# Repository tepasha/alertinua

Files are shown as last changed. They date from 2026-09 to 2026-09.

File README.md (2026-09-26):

<div align="center">

# 🚨 alertinua

**Автономна система сповіщення про повітряні тривоги в Україні на базі мікроконтролера ESP32.**






[Опис](#-опис-проєкту) •
[Підключення](#-підключення) •
[Збірка](#-збірка-й-прошивка) •
[Налаштування](#-налаштування-пристрою) •
[Архітектура](#-архітектура) •
[Тести](#-тести)

---

</div>

## 📌 Опис проєкту

**`alertinua`** — прошивка для плати **LILYGO T-Display** (ESP32, дисплей
ST7789 240×135), написана на **ESP-IDF** з FreeRTOS. Пристрій сам
підключається до Wi-Fi, раз на хвилину опитує API
[alerts.in.ua](https://alerts.in.ua/) і показує на дисплеї карту України:

| На екрані | Що означає |
| --- | --- |
| 🟥 червона область | повітряна тривога по всій області |
| 🟧 янтарна область | тривога лише в частині області (район, громада) |
| напис **ERR** | дані отримати не вдалося — старі тривоги не показуються |

Коли тривога оголошена на всю **вибрану** область, вмикається сирена
(п'єзозумер) і блимає світлодіод. Яскравість підсвітки автоматично
підлаштовується під освітлення в кімнаті. Від вбудованого акумулятора
пристрій працює без USB, а рівень заряду видно на сторінці налаштувань.

## ✨ Особливості

- 🧠 **FreeRTOS:** 7 задач, кожна зі своєю відповідальністю, обмін через
  черги, спільний стан під м'ютексом — [docs/ARCHITECTURE.md](docs/ARCHITECTURE.md).
- 📡 **Легкий обмін з API:** IoT-ендпоінт alerts.in.ua повертає рядок із
  27 символів (`A`/`P`/`N` на кожну область) — ~30 байт замість кілобайтів
  JSON, лише повітряні тривоги.
- 🌐 **Веб-налаштування:** вибір області й Wi-Fi-мережі на сторінці
  пристрою, без перепрошивки. Зберігається в NVS.
- 💡 **Адаптивна яскравість:** фоторезистор + ПІ-регулятор з anti-windup
  керує підсвіткою через ШІМ.
- 🔋 **Автономність:** акумулятор Li-Pol 3.7 В 300 мА·год у штатному
  роз'ємі плати; заряд (%, В) — на веб-сторінці й у лозі.
- 🛡️ **Надійність:** Task Watchdog на кожній задачі, валідація відповіді
  API, перепідключення Wi-Fi з експоненційною затримкою (2 → 60 с).
- 🔐 **Секрети поза git:** API-токен у файлі `.env`, TLS з перевіркою
  сертифіката.

## 🔌 Підключення

Схема підключення

| Периферія | Деталі | GPIO | Компонент коду |
| --- | --- | --- | --- |
| Дисплей ST7789 (SPI) | вбудований: MOSI / SCLK / CS / DC / RST | 19 / 18 / 5 / 16 / 23 | `map` |
| Підсвітка дисплея | вбудована, ШІМ (LEDC) | 4 | `backlight` |
| Кнопка налаштування | вбудована кнопка BOOT, переривання | 0 | `button` |
| П'єзозумер | пасивний, через резистор 220 Ом, ШІМ (LEDC) | 25 | `buzzer` |
| Світлодіод тривоги | через резистор 330 Ом | 2 | `indicators` |
| Світлодіод Wi-Fi | через резистор 330 Ом | 15 | `indicators` |
| Датчик освітлення | фоторезистор + резистор 10 кОм, ADC1_CH5 | 33 | `light_sensor` |
| Акумулятор Li-Pol | у штатний роз'єм BAT; напругу плата подає через дільник 1:2, дільник вмикає GPIO14 | 34 (АЦП), 14 (внутрішні) | `battery` |
| Вимикач живлення | з фіксацією, розриває червоний провід «+» акумулятора | — | — |

**Що потрібно докупити:** фоторезистор, резистори 10 кОм, 220 Ом і
2 × 330 Ом, два світлодіоди, пасивний п'єзозумер, акумулятор Li-Pol
602030 3.7 В 300 мА·год із платою захисту, вимикач із фіксацією
(перемикач або клавішний) для живлення від акумулятора. Без світлодіодів
прошивка працює як звичайно. Без датчика вхід GPIO33 «висить у повітрі»,
і яскравість підсвітки стрибатиме випадково — тож для автояскравості
датчик потрібен.

> Перед підключенням акумулятора звірте роз'єм і **полярність** з
> маркуванням `+`/`−` на платі: у дешевих акумуляторів дроти в роз'ємі
> бувають переставлені, а переплутана полярність може пошкодити плату.
> Вимикач ставиться в розрив червоного проводу «+». Від USB плата
> працює й при вимкненому вимикачі, але батарея тоді не заряджається.

> Датчик освітлення підключайте лише до пінів ADC1 (32, 33, 36–39): ADC2
> під час роботи Wi-Fi недоступний. GPIO34 на гребінку не виведений — він
> зайнятий вимірюванням напруги батареї.

Опис схеми й вибору деталей — [docs/PCB.md](docs/PCB.md).

## 🛠️ Збірка й прошивка

Потрібні [VS Code](https://code.visualstudio.com/) з розширенням
**PlatformIO**. Платформа `espressif32` встановлює ESP-IDF (перевірено на
6.0.1) і тулчейн сама.

1. **Токен API.** Отримайте токен на [alerts.in.ua](https://alerts.in.ua/),
   скопіюйте `.env.example` у `.env` і впишіть його:
   ```
   ALERTINUA_API_TOKEN=ваш-токен
   ```
   `.env` і згенерований з нього `env/env_config.h` у `.gitignore` —
   токен не потрапляє в git.
2. **Wi-Fi за замовчуванням (необов'язково).** Мережу простіше задати
   через [веб-налаштування](#-налаштування-пристрою). Або заздалегідь у
   `pio run -t menuconfig` → *Alertinua Configuration → Wi-Fi*.
3. **Збірка й прошивка:**
   ```
   pio run -t upload
   pio device monitor
   ```

Інші параметри (область за замовчуванням, інтервал опитування, межі
яскравості, максимальна тривалість сирени) — у
`pio run -t menuconfig` → *Alertinua Configuration*.

## ⚙️ Налаштування пристрою

1. Утримайте кнопку **BOOT** 3 секунди. Пристрій також сам переходить у
   цей режим після 10 невдалих спроб підключитися до Wi-Fi.
2. Підключіться до Wi-Fi-мережі **ESP32-Setup**.
3. Відкрийте **http://192.168.4.1/**.
4. Угорі сторінки — заряд батареї (%, В) або «Живлення від USB». Виберіть область. Щоб змінити Wi-Fi, впишіть SSID і пароль; якщо лишити
   SSID порожнім, збережена мережа не зміниться.
5. Натисніть **«Зберегти і перезавантажити»**.

## 🧩 Архітектура

```
API alerts.in.ua ──► fetch_task ──► alert_queue ──► render_task ──► дисплей
        ▲                                               │
    wifi_task                                           └──► buzzer_task (сирена)

фоторезистор ──► brightness_task (ПІ-регулятор) ──► підсвітка (ШІМ)
кнопка BOOT ──► button_task ──► режим налаштування
monitor_task: раз на 30 с — навантаження CPU кожної задачі і заряд батареї
```

Структура проєкту:

```
task/          задачі FreeRTOS — по підпапці-компоненту на кожну
components/    драйвери й логіка без власних задач:
               adc_shared, app_state, backlight, battery, brightness_ctrl,
               button, buzzer, indicators, light_sensor, map, scraping,
               settings, wifi_manager
src/           app_main() і Kconfig.projbuild (параметри menuconfig)
env/           env.py: .env → env/env_config.h перед кожною збіркою
test_host/     юніт-тести, що запускаються на комп'ютері
test_apps/     юніт-тести для запуску на самій платі
docs/          архітектура, схема підключення, опис апаратної частини
```

Детально — [docs/ARCHITECTURE.md](docs/ARCHITECTURE.md).

## 🧪 Тести

Парсер відповіді API, ПІ-регулятор яскравості і крива заряду батареї —
«чисті» функції без
залежності від обладнання, тому тестуються на звичайному комп'ютері
(фреймворк Unity):

```
sudo apt-get install --no-install-recommends libcjson-dev
make -C test_host run
```

Набір для запуску на платі — у `test_apps/` (див. коментар у
`test_apps/test_main.c`).

<div align="center">

### Слава Україні! 🇺🇦

</div>

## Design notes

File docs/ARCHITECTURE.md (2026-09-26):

# Архітектура

## 1. Чому RTOS, а не superloop

Пристрою потрібно одночасно: тримати Wi-Fi (з перепідключенням), періодично
опитувати зовнішнє REST API (мережевий I/O з тайм-аутами до 10с), малювати на
дисплеї, регулювати яскравість підсвітки за датчиком світла кожні ~0.5с,
реагувати на кнопку без затримки і керувати зумером — без того, щоб повільна
операція (HTTP-запит) блокувала швидку (регулювання яскравості, кнопка).
Один superloop із чергою `if`-ів або з `delay()` не дав би цього без
кооперативної диспетчеризації, яку FreeRTOS вже надає готовою. Тому вибір —
**FreeRTOS (RTOS)**, з окремою задачею на кожну незалежну відповідальність.

## 2. Задачі (FreeRTOS tasks)

Усі задачі лежать у папці `task/` у корені проєкту — кожна у власній
підпапці, яка є окремим компонентом ESP-IDF (`task/fetch_task/`, …).
Решта компонентів — драйвери й чиста логіка без власних задач.

| Задача | Папка (`task/`) | Пріоритет | Блокується на | Головна робота |
|---|---|---|---|---|
| `wifi_task` | `wifi_task/` | 4 | event group (тайм-аут) | підключення/перепідключення Wi-Fi, backoff, auto-provisioning |
| `fetch_task` | `fetch_task/` | 4 | `vTaskDelay` (період опитування) | HTTP GET + JSON-парсинг, шле у `alert_queue` |
| `render_task` | `render_task/` | 5 | `xQueueReceive(alert_queue)` | єдиний "письменник" framebuffer/дисплей |
| `button_task` | `button_task/` | 5 | `xQueueReceive` (ISR events) | дебаунс + вимірювання тривалості натискання |
| `buzzer_task` | `buzzer_task/` | 4 | `xQueueReceive` (команди) | неблокуюча сирена/біп |
| `brightness_ctrl_task` | `brightness_task/` | 3 | `vTaskDelay` (період регулятора) | PI-регулятор яскравості за датчиком світла |
| `monitor_task` | `monitor_task/` | 1 | `vTaskDelay` (30с) | CPU usage stats, watchdog-звіт |
| `indicators` (esp_timer callback) | indicators | — | апаратний таймер | блимання Status/Wi-Fi LED |

Мінімум "2 tasks" із п.3.1 виконано з запасом (7 задач + 1 періодичний
таймер). Кожна задача, що виконує повторювану роботу, підписана на **Task
Watchdog Timer** (`esp_task_wdt_add` + періодичний `esp_task_wdt_reset`) —
якщо якась задача зависне, пристрій сам перезавантажиться (п.5.1).

## 3. Синхронізація

```mermaid
flowchart LR
    subgraph Producers
        WT[wifi_task]
        FT[fetch_task]
        BT[button_task]
        BC[brightness_ctrl_task]
    end

    subgraph Shared["app_state (mutex-захищена структура)"]
        M((mutex))
    end

    subgraph Consumers
        RT[render_task]
        IND[indicators timer]
        MON[monitor_task]
    end

    WT -- app_state_set_wifi_status --> M
    FT -- app_state_set_alarm / set / record_fetch --> M
    BC -- app_state_set_brightness --> M
    M -- app_state_get_* --> IND
    M -- app_state_get_fetch_stats --> MON

    FT -- "alert_queue (struct, async buffer)" --> RT
    BT -. "ISR queue (gpio events)" .-> BT
    RT -- buzzer_start_alarm/stop_alarm --> BZ[buzzer_task]
```

- **Mutex** (`app_state`, `SemaphoreHandle_t`) — єдина точка правди про стан
  системи (Wi-Fi статус, чи активна тривога, яка область, яскравість,
  статистика останнього опитування). Пишуть у неї 3 різні задачі, читають —
  ще 3 інші. Критичні секції короткі (лише memcpy кількох полів), тайм-аут
  очікування mutex — 200мс (див. `app_state.c`), щоб зависання одного
  читача/писача було помітним у логах, а не тихим deadlock.
- **Queue** використано двічі, з різним призначенням:
  - `button` ISR → `button_task` (сирі події зміни рівня GPIO);
  - `fetch_task` → `render_task` (`alert_queue`, готовий результат циклу
    опитування — це і є "асинхронна передача даних" з п.2.4/3.2).
  - `buzzer` командна черга (`buzzer_task` чекає команд start/stop/beep).
- Жодна задача не читає/пише framebuffer дисплея, крім `render_task` —
  тому для нього окремий mutex не потрібен (єдиний писар за конструкцією,
  а не за домовленістю).

## 4. Діаграма станів (`app_state_t`)

```mermaid
stateDiagram-v2
    [*] --> BOOT
    BOOT --> WIFI_CONNECTING
    WIFI_CONNECTING --> FETCHING: Wi-Fi підключено
    WIFI_CONNECTING --> PROVISIONING: N невдалих спроб підряд\n(або довге натискання кнопки)
    FETCHING --> ALARM: тривога у вибраній області
    FETCHING --> CLEAR: тривоги немає
    FETCHING --> ERROR: HTTP/JSON помилка
    ALARM --> FETCHING: наступний цикл опитування
    CLEAR --> FETCHING: наступний цикл опитування
    ERROR --> FETCHING: наступний цикл опитування
    PROVISIONING --> [*]: користувач зберіг Wi-Fi\n(esp_restart)
```

`app_state_set()` (у `components/app_state`) логує кожен перехід
(`state: X -> Y`), що зручно і для налагодження, і як "живий" доказ роботи
state machine під час демонстрації (п.9.3).

## 5. Дані датчика світла → підсвітка (feedback control, п.4.1/4.2)

```mermaid
flowchart LR
    LDR[LDR + дільник\nGPIO33 / ADC1_CH5] -->|"light_sensor_read_normalized()\n0.0..1.0"| CTRL
    CTRL["PI-регулятор\n(brightness_ctrl_task)"] -->|"backlight_set_percent()"| PWM[LEDC PWM\nGPIO4]
    PWM --> BL[Підсвітка дисплея]
    CTRL -->|"app_state_set_brightness()"| STATE[(app_state)]
```

`setpoint = min + lux*(max-min)`, `error = setpoint - поточна_яскравість`,
далі класичний PI із анти-windup (обмеження інтегральної складової) і
насиченням виходу в межах `[MIN, MAX]` (Kconfig). Деталі й коефіцієнти —
`components/brightness_ctrl/brightness_ctrl_step.c` (чиста функція, покрита
хост-тестами), періодичний цикл — `task/brightness_task/brightness_task.c`.

## 6. Граф залежностей компонентів

Компоненти навмисно розбиті так, щоб не було циклів, і кожен ізольований
модуль (`button`, `buzzer`, `backlight`, `light_sensor`, `map`) не знав нічого
про решту системи — вони отримують дані через параметри функцій або нічого
не знають про `app_state` взагалі.

```mermaid
flowchart TD
    main --> app_state
    main --> indicators
    main --> wifi_manager
    main --> wifi_task
    main --> fetch_task
    main --> render_task
    main --> button_task
    main --> buzzer_task
    main --> brightness_task
    main --> monitor_task

    wifi_task --> wifi_manager
    wifi_manager --> settings
    wifi_manager --> scraping
    fetch_task --> settings
    wifi_task --> app_state
    fetch_task --> scraping
    fetch_task --> app_state
    render_task --> map
    render_task --> fetch_task
    render_task --> buzzer_task
    button_task --> button
    buzzer_task --> buzzer
    brightness_task --> brightness_ctrl
    brightness_task --> light_sensor
    brightness_task --> backlight
    brightness_task --> app_state
    monitor_task --> app_state
    monitor_task --> battery
    wifi_manager --> battery
    battery --> adc_shared
    light_sensor --> adc_shared

    indicators --> app_state
    scraping --> map
```

## 7. Відображення на дисплеї

Дані беруться з IoT-ендпоінта alerts.in.ua
`/v1/iot/active_air_raid_alerts_by_oblast.json` — це рядок із 27 символів
(`A` — тривога по всій області, `P` — у частині області, `N` — немає),
розбирається в `components/scraping/alerts_parser.c`.

`render_task` — єдина задача, що малює. Кожен кадр малюється з нуля
(`components/map/map_render.c`):
- `render_map()` — базова штрихована мапа;
- `render_mark_regions_partial()` — часткова тривога, янтарна заливка;
- `render_mark_regions_red()` — тривога по всій області, червона заливка;
- `render_draw_err_banner()` — помилка HTTP/розбору: поверх базової мапи
  лише напис "ERR", без застарілих тривог.

Міста "м. Київ" і "м. Севастополь" окремих полігонів не мають — тривога в
них показується як часткова у Київській області / Криму.

## 8. Відомі свідомі спрощення (не приховуємо)

- `wifi_manager_start_provisioning()` можна викликати і з довгого натискання
  кнопки, і автоматично з `wifi_task` після N невдалих спроб — обидва шляхи
  не координуються через окрему чергу/семафор (в оригінальному коді цей же
  ризик уже був). Малоймовірна гонитва при одночасному спрацюванні обох
  тригерів не призводить до пошкодження даних (лише до зайвого логу),
  оскільки `s_provisioning_active` перевіряється перед стартом SoftAP.
- Один HTTP-буфер (8КБ, `static` у `fetch_task`) виділений один раз назавжди,
  а не на кожен цикл — свідомо, щоб уникнути фрагментації купи (heap) і
  повторних malloc/free (п.6.3).

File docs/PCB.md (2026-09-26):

# Апаратна частина

## Схема підключення

Схема підключення

`docs/wiring.svg` — схема з'єднань зовнішніх деталей з гребінкою LILYGO
T-Display. Дисплей, його підсвітка й кнопка BOOT уже є на платі.
Принципова схема в KiCad — у роботі.

## Що на схемі

| Позначення | Що це | GPIO | Примітка |
|---|---|---|---|
| BUZ1 | П'єзозумер | GPIO25 (LEDC, PWM) | R1 (220R) обмежує струм через п'єзоелемент |
| ST7789 (BL) | Підсвітка дисплея | GPIO4 (LEDC, PWM) | вбудована; керується `brightness_task` (ПІ-регулятор) |
| SW1 | Кнопка входу в налаштування Wi-Fi | GPIO0 | вбудована BOOT-кнопка плати, зовнішня не потрібна |
| LED1 + R2 | Індикатор тривоги | GPIO2 | R2 330 Ом обмежує струм; блимає, поки тривога активна |
| LED2 + R3 | Індикатор Wi-Fi | GPIO15 | R3 330 Ом; горить постійно / блимає / вимкнено залежно від статусу |
| LDR1 + R4 | Дільник напруги з фоторезистором (датчик освітлення) | GPIO33 (ADC1_CH5) | R4 10 кОм; ADC1, бо ADC2 не працює разом із Wi-Fi |
| SW2 | Вимикач живлення з фіксацією | — | у розриві червоного проводу «+» між акумулятором і роз'ємом BAT; при вимкненому SW2 плата живиться лише від USB, батарея не заряджається |
| BAT1 | Акумулятор Li-Pol 602030, 3.7 В, 300 мА·год, з платою захисту | GPIO34 (ADC1_CH6), GPIO14 | у штатний роз'єм BAT; заряджає вбудований контролер від USB. Напругу плата подає на GPIO34 через дільник 100к/100к, дільник вмикається HIGH на GPIO14 |

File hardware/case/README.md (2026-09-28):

# Корпус alertinua для 3D-друку

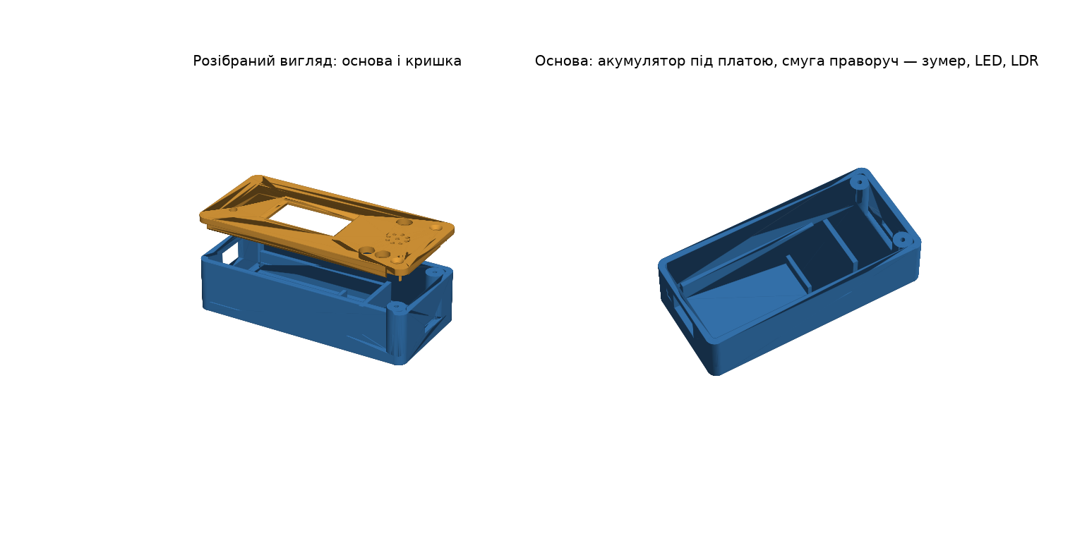
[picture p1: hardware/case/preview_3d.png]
Прев'ю


Компактний корпус **76 × 36 × 20 мм** із двох частин. Акумулятор лежить
**під платою**, між напрямними, тому праворуч від плати лишається лише
вузька смуга під зумер, світлодіоди, фоторезистор і вимикач.

- **основа** — напрямні під LILYGO T-Display (висота 7 мм), під ними —
  акумулятор 602030 з упором, отвір під USB-C (зліва), проріз під вимикач
  SS-12D00 (справа, внизу), 2 стійки під саморізи M2 у правих кутах;
- **кришка** — вікно екрана з фаскою, отвір ⌀3 мм до кнопки BOOT, 2 отвори
  під світлодіоди 5 мм, отвір під фоторезистор 5 мм, решітка й тримач
  зумера ⌀12 мм, посадковий бортик. Ліву частину кришки тримає бортик,
  праву — 2 гвинти M2.

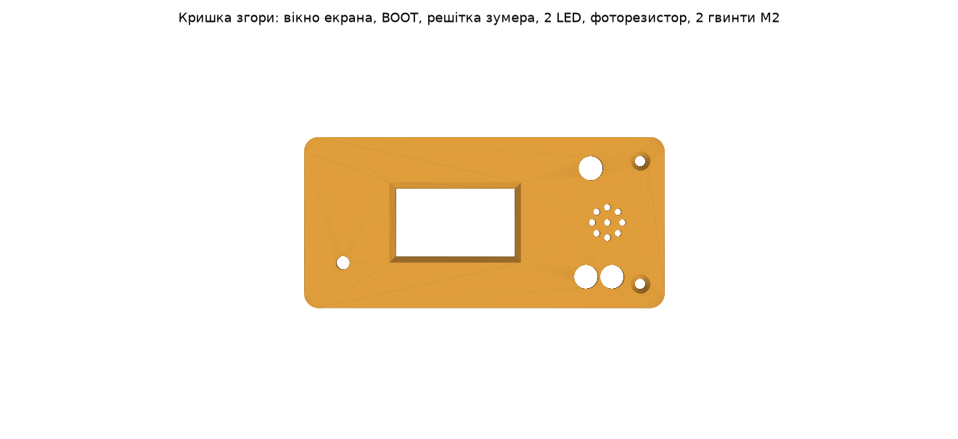
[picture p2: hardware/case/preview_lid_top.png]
Кришка згори


## Файли

| Файл | Для чого |
| --- | --- |
| `alertinua_base.stl`, `alertinua_lid.stl` | слайсер; вже в положенні для друку (основа дном, кришка лицем на столі) |
| `alertinua_case.FCStd` | редагування у FreeCAD |
| `alertinua_base.step`, `alertinua_lid.step` | інші CAD-програми |
| `alertinua_case.py` | параметричний скрипт, з якого згенеровано все вище |

## Перед друком — виміряти

Ці розміри в скрипті — оцінки (позначені `ВИМІРЯТИ`). Звірте їх
штангенциркулем, змініть у `alertinua_case.py` і перегенеруйте:

1. `DISP_CX`, `DISP_CY` — центр екрана на платі (найважливіше).
2. `BOOT_X`, `BOOT_Y` — положення кнопки BOOT.
3. `USB_CZ` — висота роз'єму USB-C над дном (отвір має запас).
4. `BUZ_D` — діаметр зумера (зараз 12 мм).
5. `BATT_L` — довжина акумулятора разом із платою захисту (зараз 34 мм).
6. **Що стирчить знизу плати.** Під платою лишається 7 мм, акумулятор —
   6 мм. Якщо роз'єм BAT чи інші деталі на звороті T-Display виступають
   більше ніж на 1 мм, збільште `IN_H`
   (висоту корпусу) на потрібну величину.

Перегенерувати:

```
freecadcmd alertinua_case.py
```

Файли з'являться в папці `out/` поруч зі скриптом.

## Друк

PLA або PETG, шар 0.2 мм, заповнення 20 %, без підтримок. Спершу варто
надрукувати лише кришку й приміряти до плати — це швидко покаже, чи
правильно стоїть вікно екрана.

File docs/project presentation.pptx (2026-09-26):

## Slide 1

ДИПЛОМНИЙ ПРОЄКТ

alertinua

Розробка вбудованої системи моніторингу повітряних тривог на базі мікроконтролера ESP32

Терехов Павло

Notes: Шановні члени екзаменаційної комісії! Мене звати [ПІБ], я студент групи [група]. Представляю дипломний проєкт на тему «Розробка вбудованої системи моніторингу повітряних тривог на базі мікроконтролера ESP32». Мій науковий керівник — [ПІБ керівника].

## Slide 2

АКТУАЛЬНІСТЬ

Навіщо окремий пристрій

Телефон не завжди поруч

Розряджений, у беззвучному режимі або в іншій кімнаті.

Карта з першого погляду

Стан усіх областей одразу, без відкривання застосунків.

Надійність критична

Зависання чи застарілі дані для сповіщувача неприйнятні.

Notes: Повітряна тривога в Україні — частина щоденного життя. Люди стежать за нею через застосунки на смартфоні, але телефон буває розряджений, у беззвучному режимі або просто не під рукою. Потрібен окремий пристрій, який постійно працює, наприклад на столі чи біля входу. Він має з першого погляду показувати ситуацію по всій країні й подавати звуковий сигнал, коли тривога у вашій області. Готові рішення на кшталт настінних мап існують, але їх зазвичай роблять як аматорські проєкти. Там мало уваги приділяють надійності: пристрій може зависнути під час обриву Wi-Fi чи після некоректної відповіді сервера, і тоді показує застарілі дані. Для пристрою, який сповіщає про небезпеку, це неприйнятно.

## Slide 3

МЕТА І ЗАДАЧІ

Автономний пристрій, що в реальному часі показує карту повітряних тривог України і стабільно працює без втручання користувача.

01

Дані з API alerts.in.ua

02

Карта областей з тривогами

03

Сирена для вибраної області

04

Налаштування без перепрошивки

05

Стабільність при збоях мережі й сервера

06

Автоматичні тести ключової логіки

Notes: Мета роботи — розробити автономний пристрій, який у реальному часі показує карту повітряних тривог України і стабільно працює без втручання користувача. Для цього я поставив такі задачі: отримувати дані з офіційного API сервісу alerts.in.ua; відображати на дисплеї карту областей з тривогами; сповіщати звуком про тривогу у вибраній області; забезпечити налаштування пристрою без перепрошивки; гарантувати стабільну роботу при збоях мережі й сервера; покрити ключову логіку автоматичними тестами.

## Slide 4

АПАРАТНА ЧАСТИНА

LILYGO T-Display на ESP32

Компонент | Призначення | GPIO
П'єзозумер | сирена, ШІМ | 25
Фоторезистор | автояскравість, АЦП | 33
Підсвітка | яскравість, ШІМ | 4
Кнопка BOOT | режим налаштування | 0
Світлодіоди | стан і Wi-Fi | 2, 15
Акумулятор Li-Pol | автономність, заряд у веб | 34

Вбудований Wi-Fi, два ядра й апаратний TLS за невисокої ціни.

Кольоровий дисплей ST7789, 240×135 пікселів.

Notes: Основа пристрою — плата LILYGO T-Display з мікроконтролером ESP32 і кольоровим дисплеєм ST7789 на 240×135 пікселів. ESP32 я вибрав, бо він має вбудований Wi-Fi, два ядра й апаратну підтримку TLS за невисокої ціни. До плати підключено: п'єзозумер для сирени, що керується через ШІМ (модуль LEDC); фоторезистор на вході АЦП для автоматичного регулювання яскравості; два світлодіоди для індикації стану системи й Wi-Fi; вбудовану кнопку BOOT, через яку вмикається режим налаштування; акумулятор Li-Pol 602030 на 3.7 В і 300 мА·год із платою захисту — у штатний роз'єм плати, його заряд плата вимірює на GPIO34 і показує на веб-сторінці.

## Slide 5

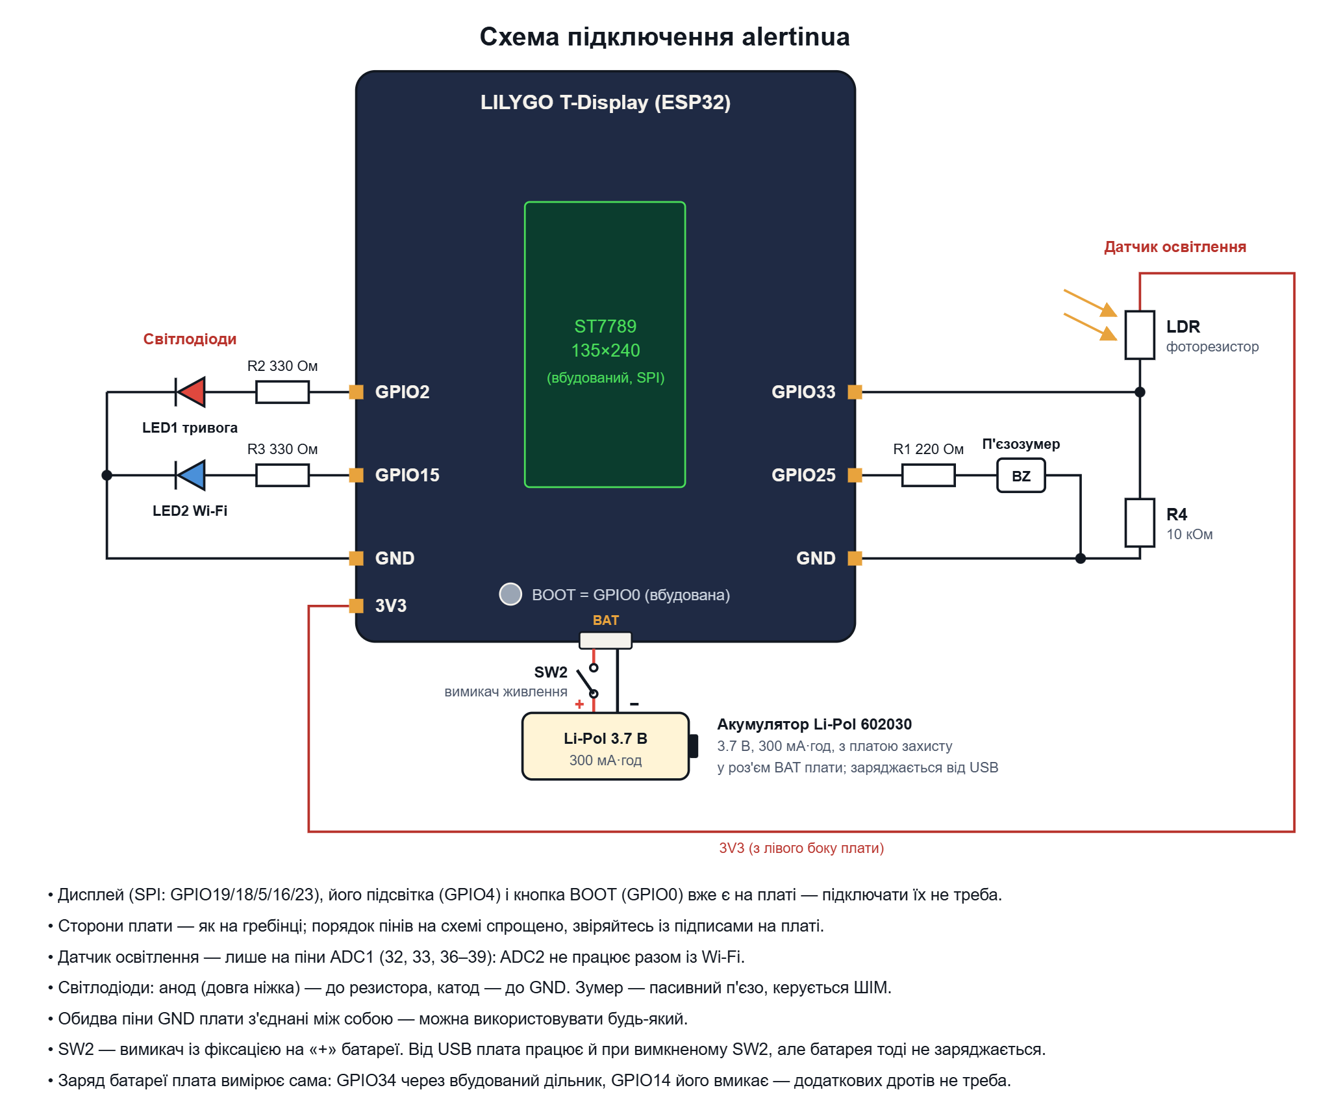
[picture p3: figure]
Схема підключення: фоторезистор і резистор 10 кОм до GPIO33, зумер через 220 Ом до GPIO25, світлодіоди через 330 Ом до GPIO2 і GPIO15, акумулятор Li-Pol через вимикач у роз'єм BAT

СХЕМА ПІДКЛЮЧЕННЯ

Що підключається до плати

Дисплей, підсвітка й кнопка BOOT уже є на платі.

Фоторезистор — на ADC1 (GPIO33), бо ADC2 не працює разом із Wi-Fi.

Акумулятор — у штатний роз'єм BAT, через вимикач на «+».

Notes: Зовнішніх деталей небагато. Дисплей, його підсвітка й кнопка BOOT уже є на самій платі. Ліворуч, біля GPIO2 і GPIO15, — світлодіоди: тривоги через резистор 330 Ом на GPIO2 і Wi-Fi через 330 Ом на GPIO15. Праворуч — датчик освітлення і зумер. Фоторезистор і резистор 10 кОм утворюють дільник напруги, середня точка йде на GPIO33 — це вхід ADC1, бо АЦП другого блоку під час роботи Wi-Fi недоступний. Живлення 3V3 для дільника береться з лівого боку плати. Пасивний п'єзозумер підключено через резистор 220 Ом до GPIO25 (ШІМ). Знизу — акумулятор Li-Pol 602030, 3.7 В, 300 мА·год із платою захисту. Він вставляється у штатний роз'єм BAT, заряджається від USB вбудованим контролером. Напругу батареї плата подає на GPIO34 через дільник, тож для показника заряду додаткові дроти не потрібні. У розриві червоного проводу «+» стоїть вимикач живлення з фіксацією SW2: ним пристрій вимикається, коли працює від батареї.

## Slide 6

АРХІТЕКТУРА ПЗ

7 задач FreeRTOS на ESP-IDF

API alerts.in.ua

fetch_task

alert_queue

render_task

Дисплей і сирена

Паралельно працюють:

wifi_task

Wi-Fi і перепідключення

buzzer_task

неблокуюча сирена

button_task

кнопка через переривання

brightness_task

ПІ-регулятор яскравості

monitor_task

навантаження CPU

Черги FreeRTOS для обміну даними · м'ютекс для спільного стану · кожна задача — окремий компонент

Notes: Програмне забезпечення написано мовою C на фреймворку ESP-IDF у середовищі PlatformIO. В основі — операційна система реального часу FreeRTOS. Чому не простий нескінченний цикл? Пристрій має одночасно тримати Wi-Fi, робити мережеві запити, що можуть тривати секунди, малювати на дисплеї, реагувати на кнопку і регулювати яскравість. В одному циклі повільний HTTP-запит блокував би все інше. Тому систему розбито на сім задач FreeRTOS, у кожної своя відповідальність. Головний потік даних: fetch_task отримує дані з API й кладе результат у чергу, render_task забирає його, малює карту і за потреби вмикає сирену. Паралельно працюють задачі Wi-Fi, сирени, кнопки, яскравості та моніторингу. Задачі обмінюються даними через черги FreeRTOS, а спільний стан захищено м'ютексом. Код поділено на незалежні компоненти: драйвери обладнання окремо, задачі окремо.

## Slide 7

ДАНІ ТА ВІДОБРАЖЕННЯ

27 символів замість кілобайтів JSON

NNNNNNNNNNANNNNNNNNNNPNNNNN

IoT-ендпоінт alerts.in.ua: один символ на область, ~30 байт, лише повітряні тривоги

A — тривога по всій області: червона

P — у частині області: янтарна

ERR

помилка — без застарілих даних

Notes: Спершу я використовував загальний ендпоінт API, який повертає повний список тривог у форматі JSON. Під час масових тривог така відповідь виявилася завеликою для пам'яті мікроконтролера. До того ж вона містила й інші типи загроз, наприклад загрозу артобстрілу. Тому я перейшов на спеціальний IoT-ендпоінт alerts.in.ua. Він повертає рядок лише з 27 символів, по одному на кожну область: A — тривога по всій області, P — у частині області, N — тривоги немає. Відповідь займає близько 30 байт замість кількох десятків кілобайт. На дисплеї червоним позначено області, де тривога на всю територію, янтарним — області з частковою тривогою. Якщо дані отримати не вдалося, на екрані напис ERR. Важливе рішення: кожен кадр малюється з нуля. Застарілі дані не лишаються на екрані після помилки, бо показати користувачу стару «відсутність тривоги» небезпечніше, ніж чесно показати помилку.

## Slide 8

НАДІЙНІСТЬ

Пристрій не зависає і не бреше

Watchdog-таймер

Кожна задача під наглядом; зависання — автоматичне перезавантаження.

Валідація даних

Неправильна довжина, символ чи JSON — відповідь відхиляється.

Мережа

Перепідключення із затримкою від 2 до 60 с, далі — режим налаштування.

Безпека

TLS з перевіркою сертифіката; токен у файлі .env, поза git.

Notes: Надійності я приділив найбільше уваги. Watchdog-таймер: кожна задача підписана на апаратний сторожовий таймер. Якщо будь-яка задача зависне, пристрій сам перезавантажиться. Усі довгі очікування розбито на короткі інтервали, щоб таймер не спрацьовував хибно. Валідація даних: парсер відхиляє будь-яку некоректну відповідь — неправильну довжину, невідомий символ, зіпсований JSON. Мережа: перепідключення з експоненційною затримкою від 2 до 60 секунд, щоб не перевантажувати мережу. Після серії невдач пристрій сам переходить у режим налаштування. Безпека: з'єднання з API захищене TLS з перевіркою сертифіката. API-токен зберігається у файлі .env, який не потрапляє в систему контролю версій.

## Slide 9

НАЛАШТУВАННЯ І ЯСКРАВІСТЬ

Без програмування й без перепрошивки

Веб-налаштування

1. Утримати кнопку BOOT 3 с
2. Підключитися до мережі «ESP32-Setup»
3. Відкрити 192.168.4.1
4. Вибрати область і Wi-Fi

Вибір зберігається в NVS і переживає перезавантаження.

Адаптивна яскравість

ПІ-регулятор з anti-windup плавно підлаштовує підсвітку під освітлення в кімнаті.

setpoint = min + lux · (max − min)

Вночі дисплей не сліпить, удень його добре видно.

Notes: Налаштувати пристрій може будь-хто без програмування. Досить утримати кнопку три секунди, і пристрій створить власну Wi-Fi-мережу з веб-сторінкою. На ній можна вибрати свою область і домашню мережу. Налаштування зберігаються в енергонезалежній пам'яті (NVS). Яскравість підсвітки регулюється замкненим контуром керування: ПІ-регулятор з обмеженням інтегральної складової (anti-windup) порівнює бажану яскравість, яка залежить від освітлення, з поточною і плавно її коригує. Вночі дисплей не сліпить, а вдень його добре видно.

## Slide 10

ТЕСТУВАННЯ

Ключова логіка покрита тестами Unity

16

тестів парсера відповіді API

9

тестів ПІ-регулятора яскравості

25/25

проходять успішно

Логіка винесена в «чисті» функції без залежності від обладнання: тести йдуть на комп'ютері, окремий набір — на самій платі.

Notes: Ключову логіку винесено в «чисті» функції, які не залежать від обладнання. Тому їх можна тестувати на звичайному комп'ютері фреймворком Unity, тим самим, що вбудований в ESP-IDF. 16 тестів парсера відповіді API: пошкоджені дані, граничні випадки, відображення міст Київ і Севастополь на області. 9 тестів регулятора яскравості: збіжність, межі, anti-windup, поведінка при відмові датчика. Усі тести проходять успішно. Окремо підготовано набір тестів, які запускаються безпосередньо на мікроконтролері.

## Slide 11

РЕЗУЛЬТАТИ

Що зроблено

Пристрій показує карту тривог по всіх областях і подає сигнал для вибраної

Багатозадачна архітектура на FreeRTOS із сімома задачами

Захист від зависань, збоїв мережі й некоректних даних

Налаштування через веб-інтерфейс без перепрошивки

Ключова логіка покрита автоматичними тестами

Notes: Отже, в межах проєкту: розроблено пристрій, який показує карту тривог по всіх областях України і подає звуковий сигнал для вибраної області; побудовано багатозадачну архітектуру на FreeRTOS із сімома задачами; реалізовано захист від зависань, збоїв мережі й некоректних даних; зроблено налаштування через веб-інтерфейс без перепрошивки; покрито ключову логіку автоматичними тестами. [Сюди варто додати виміряні на платі числа: час запиту, навантаження процесора з логу monitor_task, використання RAM і flash.]

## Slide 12

ПЕРСПЕКТИВИ

Куди розвивати далі

Налаштування за IP-адресою в домашній мережі

Оновлення прошивки «по повітрю» (OTA)

Відображення інших типів загроз

Власна друкована плата й корпус

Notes: Проєкт можна розвивати далі: доступ до сторінки налаштувань у звичайному режимі роботи, за IP-адресою в домашній мережі; оновлення прошивки «по повітрю» (OTA); відображення інших типів загроз; власна друкована плата й корпус для серійного виготовлення.

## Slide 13

Дякую за увагу!

alertinua · ESP32 · FreeRTOS · alerts.in.ua · created

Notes: Дякую за увагу! Готовий відповісти на ваші запитання. Можливі запитання: чому ESP32, а не Raspberry Pi; що буде, якщо API недоступний; як часто оновлюються дані; чому сирена лише при тривозі на всю область; як вирішено синхронізацію задач; навіщо ПІ-регулятор. Відповіді — у документі з промовою.

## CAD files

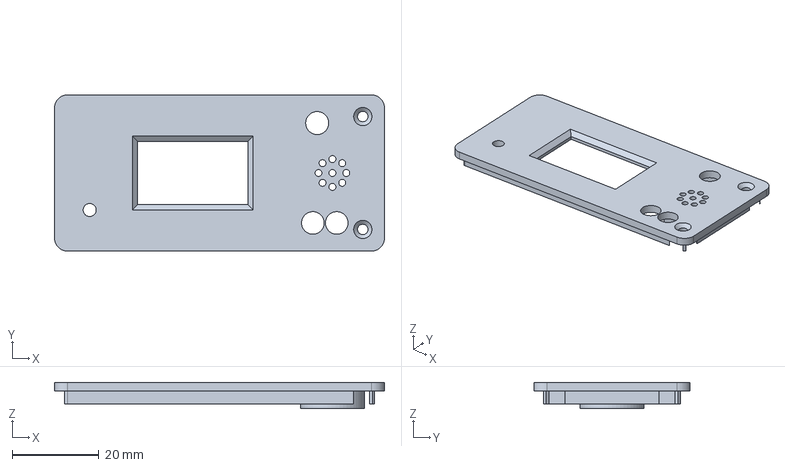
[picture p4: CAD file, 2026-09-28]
hardware/case/alertinua_lid.step
76.0 x 36.0 x 6.00 mm

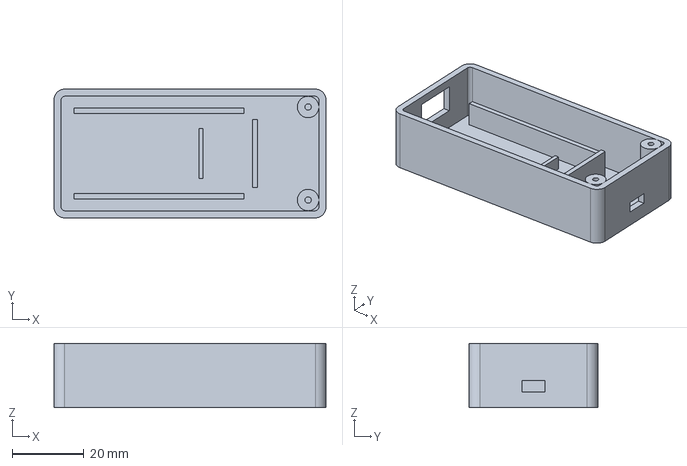
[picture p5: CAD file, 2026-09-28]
hardware/case/alertinua_base.step
76.0 x 36.0 x 18.0 mm

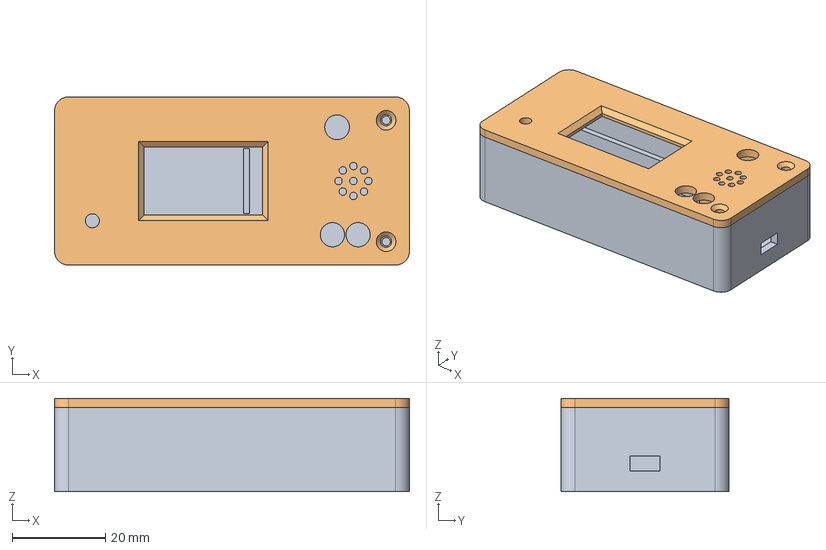
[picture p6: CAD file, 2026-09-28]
hardware/case/alertinua_case.FCStd
76.0 x 36.0 x 20.0 mm
Base
Lid

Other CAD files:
hardware/case/alertinua_base.stl
hardware/case/alertinua_lid.stl

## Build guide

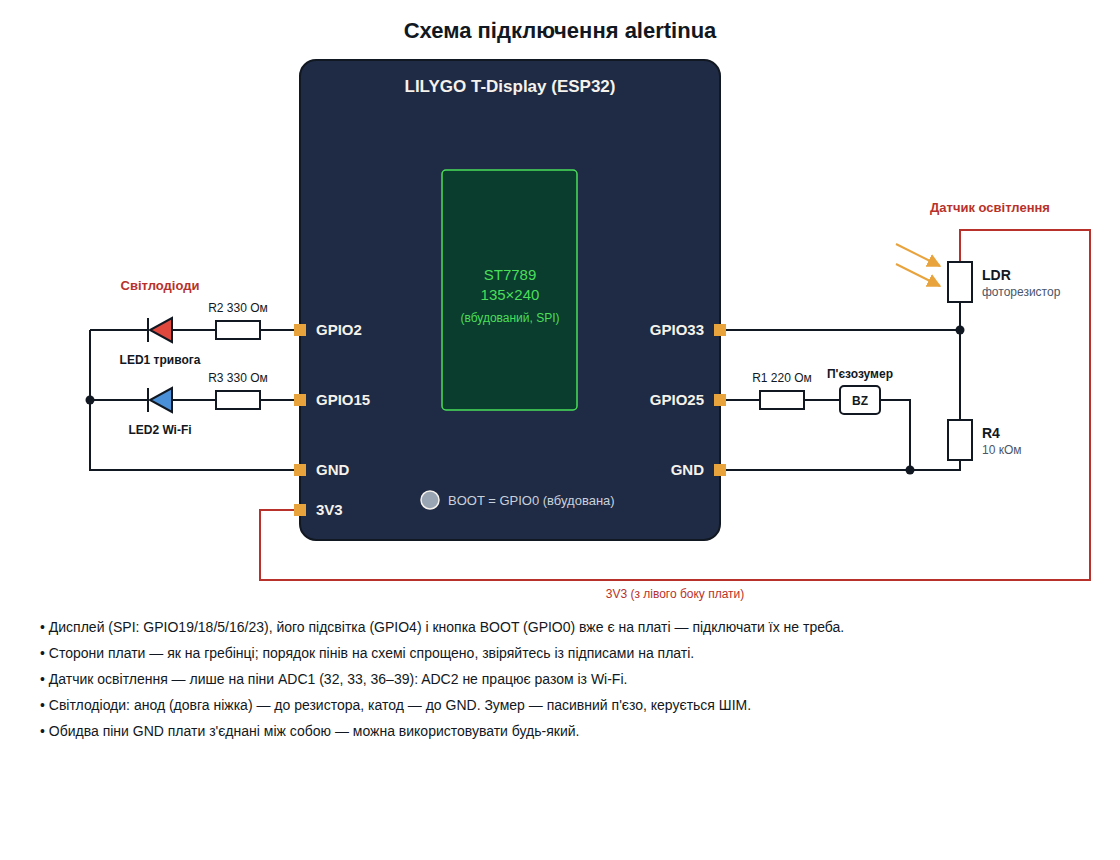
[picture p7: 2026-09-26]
docs/wiring.png

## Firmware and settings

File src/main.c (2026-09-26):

#include "freertos/FreeRTOS.h"
#include "freertos/queue.h"

#include "esp_log.h"
#include "esp_err.h"
#include "esp_system.h"
#include "nvs_flash.h"

#include "app_state.h"
#include "indicators.h"
#include "battery.h"
#include "wifi_manager.h"

/* Усі задачі FreeRTOS живуть у task/ - по папці-компоненту на задачу */
#include "alert_msg.h"
#include "wifi_task.h"
#include "fetch_task.h"
#include "render_task.h"
#include "button_task.h"
#include "buzzer_task.h"
#include "brightness_task.h"
#include "monitor_task.h"

static const char *TAG = "MAIN";

static void on_setup_button_long_press(void) {
    wifi_manager_start_provisioning();
}

void app_main(void) {
    esp_err_t ret = nvs_flash_init();
    if (ret == ESP_ERR_NVS_NO_FREE_PAGES || ret == ESP_ERR_NVS_NEW_VERSION_FOUND) {
        ESP_ERROR_CHECK(nvs_flash_erase());
        ret = nvs_flash_init();
    }
    if (ret != ESP_OK) {
        ESP_LOGE(TAG, "nvs_flash_init: %s - Wi-Fi креденшли/provisioning можуть не працювати",
                 esp_err_to_name(ret));
    }

    ESP_ERROR_CHECK(app_state_init());

    // Черга fetch_task -> render_task
    QueueHandle_t alert_queue = xQueueCreate(4, sizeof(alert_msg_t));
    if (alert_queue == NULL) {
        ESP_LOGE(TAG, "не вдалось створити alert_queue - перезавантаження");
        esp_restart();
    }

    indicators_init();
    if (battery_init() != ESP_OK) {
        ESP_LOGW(TAG, "не вдалось ініціалізувати вимірювання батареї");
    }
    brightness_task_start();
    buzzer_task_start();
    button_task_start(SETUP_BUTTON_GPIO, LONG_PRESS_MS, on_setup_button_long_press);

    render_task_start(alert_queue);
    fetch_task_start(alert_queue);
    monitor_task_start();

    wifi_task_start();

    ESP_LOGI(TAG, "alertinua: усі фонові задачі запущені, app_main завершується");
}

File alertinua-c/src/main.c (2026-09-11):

#include <esp_log.h>
#include <nvs_flash.h>
#include "esp_lcd_panel_io.h"
#include "esp_lcd_panel_ops.h"

#include "components/wifi_manager/wifi_manager.h"
#include "components/map/map_render.h"
#include "components/button/button.h"
#include "components/scraping/scraping.h"

static const char *TAG = "MAIN";

static void on_setup_button_long_press() {
    wifi_manager_start_provisioning();
}

void app_main() {
    static esp_err_t err;

    //init display
    esp_lcd_panel_handle_t panel = display_init();
    uint16_t *fb = heap_caps_malloc(MAP_DISPLAY_W * MAP_DISPLAY_H * sizeof(uint16_t), MALLOC_CAP_DMA);
    if (fb == NULL) {
        ESP_LOGE(TAG, "Не вдалось виділити framebuffer (%d байт)",
                 (int)(MAP_DISPLAY_W * MAP_DISPLAY_H * sizeof(uint16_t)));
        return;
    }

    // read token from .env file
    ESP_LOGE(TAG, "Read API: %s, Token: %s", ALERT_API, ALERT_TOKEN);

    if (!ALERT_API || !ALERT_TOKEN) {
        ESP_LOGE(TAG, "Can't read API and Token");
        render_draw_err_banner(fb);
    }

    //wifi
    esp_err_t ret = nvs_flash_init(); // required by WiFi and by wifi_creds
    if (ret == ESP_ERR_NVS_NO_FREE_PAGES || ret == ESP_ERR_NVS_NEW_VERSION_FOUND) {
        err = nvs_flash_erase();
        if (err != ESP_OK) {
            ESP_LOGE(TAG, "nvs_flash_erase: %d", err);
            render_draw_err_banner(fb);
        }
        ret = nvs_flash_init();
    }

    err = ret;
    if (err != ESP_OK) {
        ESP_LOGE(TAG, "ret: %d", err);
        render_draw_err_banner(fb);
    }

    if (!wifi_manager_connect_sta()) {
        ESP_LOGE(TAG, "Failed to connect to WiFi. Hold the setup button for %d s to reconfigure.",
                 LONG_PRESS_MS / 1000);
        button_start_long_press_watch(SETUP_BUTTON_GPIO, LONG_PRESS_MS, on_setup_button_long_press);
    } else {
        //scraping
        static char response_body[2048];
        int status = api_fetch_bearer_auth(ALERT_API, ALERT_TOKEN, response_body);
        if (status >= 200 && status < 300) {
            ESP_LOGI(TAG, "Response body:\n%s", response_body);
        } else {
            ESP_LOGE(TAG, "Fetch failed, status: %d", status);
            render_draw_err_banner(fb);
        }
    }

    err = esp_lcd_panel_draw_bitmap(panel, 0, 0, MAP_DISPLAY_W, MAP_DISPLAY_H, fb);
    if (err != ESP_OK) {
        ESP_LOGE(TAG, "esp_lcd_panel_draw_bitmap: %d", err);
    }
}

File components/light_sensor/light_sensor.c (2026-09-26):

#include <stdbool.h>

#include "esp_log.h"

#include "adc_shared.h"
#include "light_sensor.h"

#define LIGHT_SENSOR_ADC_CHANNEL ADC_CHANNEL_5 /* GPIO33 на ADC1 оригінального ESP32 */
#define LIGHT_SENSOR_ADC_MAX_RAW 4095           /* 12-бітний АЦП */

static const char *TAG = "LIGHT_SENSOR";
static bool s_ready = false;

esp_err_t light_sensor_init(void) {
    esp_err_t err = adc1_shared_add_channel(LIGHT_SENSOR_ADC_CHANNEL);
    if (err != ESP_OK) {
        return err;
    }
    s_ready = true;
    return ESP_OK;
}

float light_sensor_read_normalized(void) {
    if (!s_ready) {
        return -1.0f;
    }

    int raw = 0;
    esp_err_t err = adc1_shared_read_raw(LIGHT_SENSOR_ADC_CHANNEL, &raw);
    if (err != ESP_OK) {
        ESP_LOGW(TAG, "adc1_shared_read_raw: %s", esp_err_to_name(err));
        return -1.0f; // помилка периферії - хай викликач вирішує (тримати останнє значення)
    }

    return (float)raw / (float)LIGHT_SENSOR_ADC_MAX_RAW;
}

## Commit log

2026-08-23 fix include and add buzzer
    [buzzer.c]
2026-08-23 add play siren for buzzer
    [buzzer.c, main.c]
2026-09-23 refactor main and rendering
    [alertinua.kicad_sch]
2026-09-26 remove hardware schema
    [alertinua.kicad_sch]
2026-09-28 Add 3D-printable case (FreeCAD model, STL, STEP)
    Two-part enclosure 104x42x20 mm for LILYGO T-Display, Li-Pol 602030
    battery, buzzer, LEDs, LDR and power switch. Generated by the
    parametric FreeCAD script alertinua_case.py; dimensions marked
    ВИМІРЯТИ are estimates to verify before printing.
    Claude-Session: https://claude.ai/code/session_01Y2NxhHV2ssCHvSWf5b4hkF
    [alertinua_base.step, alertinua_base.stl, alertinua_case.FCStd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]
2026-09-28 Make case compact: battery under the board (76x36x20 mm)
    The battery now lies under the T-Display between the board rails, so
    only a narrow strip for the buzzer, LEDs, LDR and switch remains to the
    right. Outer size shrinks from 104x42x20 to 76x36x20 mm; the lid is
    held by the lip on the left and 2 M2 screws on the right.
    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
    [alertinua_base.step, alertinua_base.stl, alertinua_case.FCStd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]

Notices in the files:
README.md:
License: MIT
